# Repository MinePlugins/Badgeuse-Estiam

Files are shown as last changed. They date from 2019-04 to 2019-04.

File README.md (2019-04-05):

# Badgeuse-Estiam  :credit_card: 	

Réalisation complète du code de la badgeuse (API Désactivé et Token retiré)

# Dépendences  :package:

- Python 3
  - Flask
  - Flask_SocketIO
  - graphqlclient
  - PySerial
- Lecteur RFID Arduino (Le code à upload est dans Arduino)

# Matériels  :package:

- Ecran 7" HDMI
- Un Raspberry Pi
- Un Arduino
- Un RFID Reader RC522
- Des badges RFID (Mifare classic)

# Montage du Lecteur  :wrench:

```text
RC522   | Arduino Pin
  VCC   |  +5V
  RST   |   9
  GND   |   GND
  MISO  |   12
  MOSI  |   11
  SCK   |   13
  NSS   |   10
  IRC   |   /
  ```

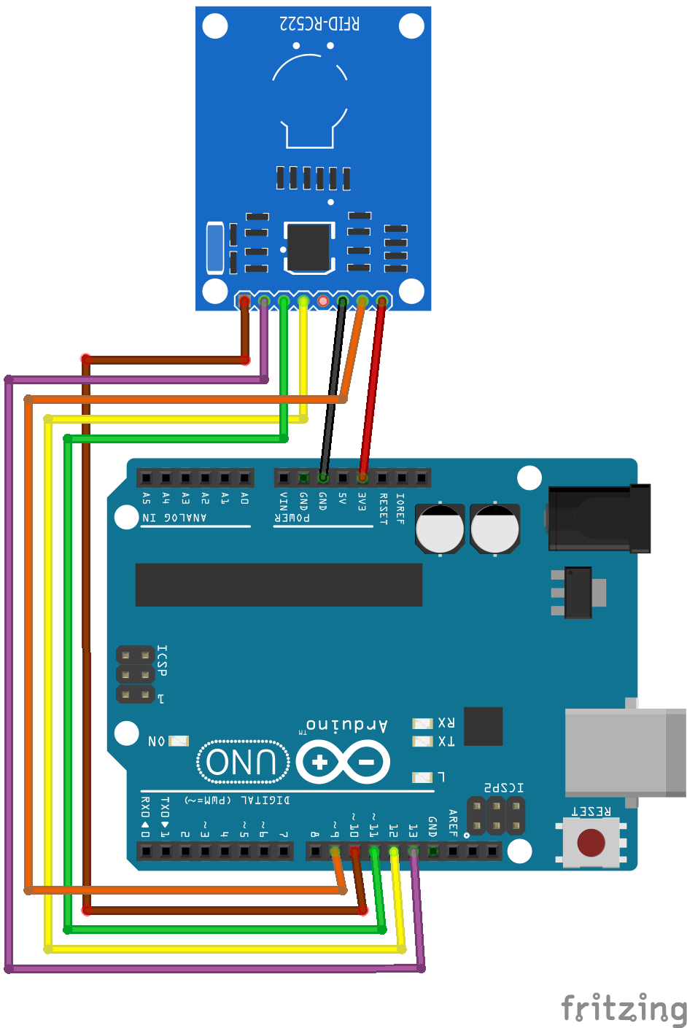
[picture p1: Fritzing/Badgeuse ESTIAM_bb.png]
Montage


# Configuration du Raspberry Pi:strawberry: :pencil2:
Tous d'abord il faut téléchargé le projet et l'installer sur le Raspberry Pi :
```bash
sudo apt-get install git python3-pip -y
sudo git clone https://github.com/MinePlugins/Badgeuse-Estiam
pip install -r requirements.txt
```
Puis il faut faire démarrer le script python, chromium en mode kiosk et de désactiver la souris à chaque démarrage
pour ce faire il faut édité le fichier `/home/pi/.config/lxsession/LXDE-pi○/autostart`.
Remplacer les lignes par celle-ci :

```bash
@python3 /home/pi/app.py
@sleep 10
@chromium-browser --incognito --kiosk http://127.0.0.1:8000
@unclutter -idle 0
```

Puis pour préserver la planète :earth_americas: nous allons faire une tâche cron qui éteint l'écran tous les soir à 19h du lundi au vendredi et une autre tâche qui allume tous les jour du lundi au vendredi à 8h

```bash
crontab -e

0 8 * * 1-5 vcgencmd display_power 1 >/dev/null 2>&1
0 19 * * 1-5 vcgencmd display_power 0 >/dev/null 2>&1

```

Enfin redémmarer les Raspberry Pi normalement tous s'allume correctement (si il est connecté à internet)
```bash
sudo reboot
```
# UI

[Lien .pdf du design](https://github.com/MinePlugins/Badgeuse-Estiam/raw/master/Design/Design%20Badgeuse.pdf)

## Présentation

Voilà le résultat final :

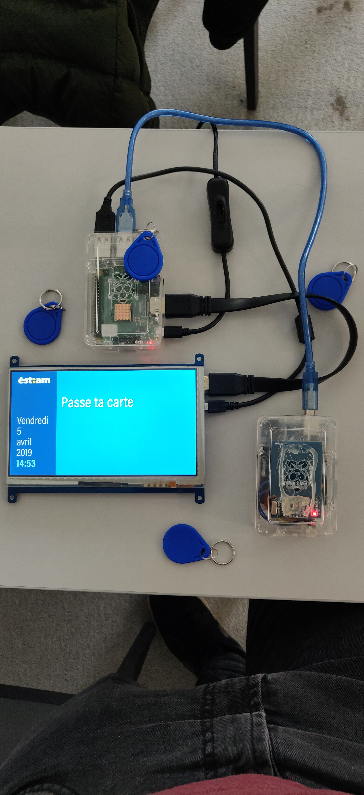
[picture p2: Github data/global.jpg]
Final


En cas d'erreur :

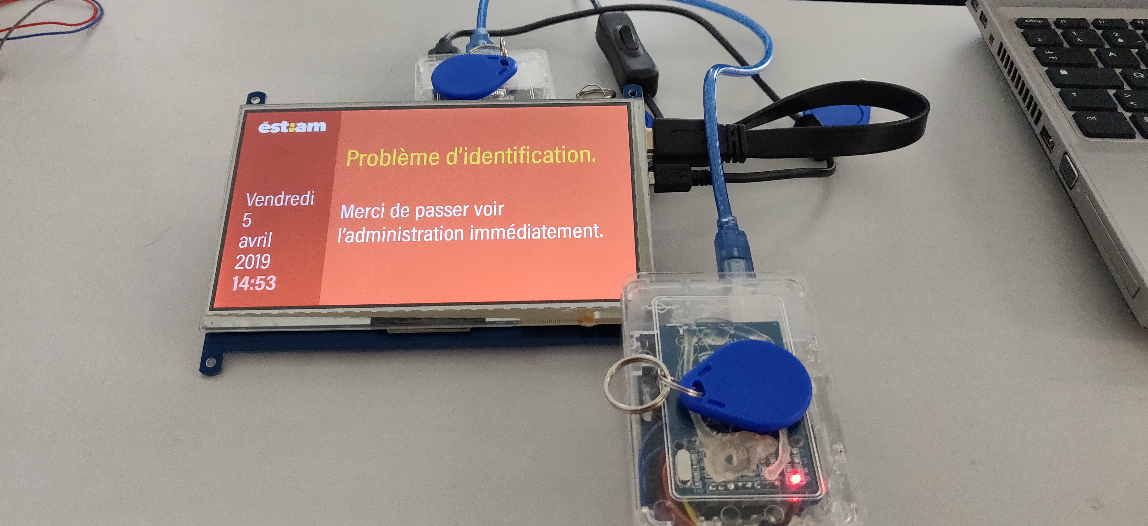
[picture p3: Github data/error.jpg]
Error


En en fonctionnement normal :

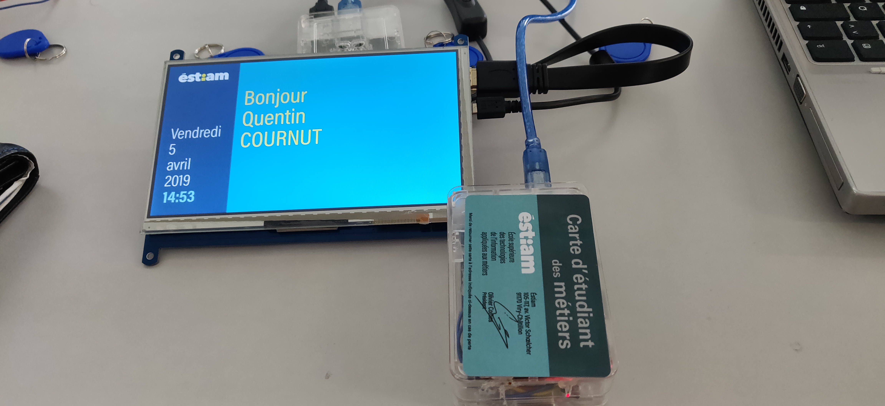
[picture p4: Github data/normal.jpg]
Normal


En cas de dysfonctionnement :

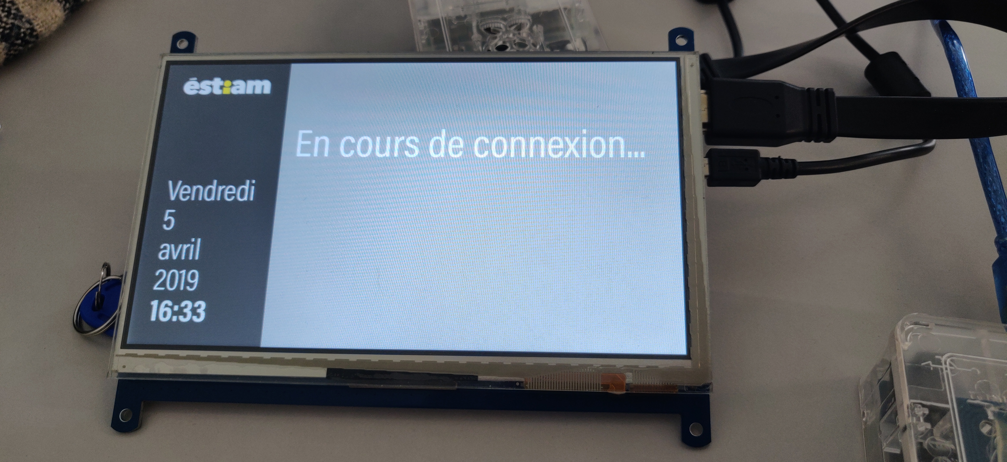
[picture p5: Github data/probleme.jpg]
Dys


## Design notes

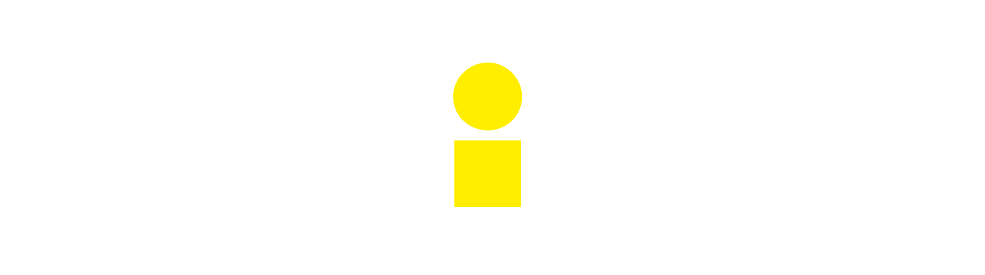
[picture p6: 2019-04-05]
static/e263796130a8c5083d48e29151d031ba.png

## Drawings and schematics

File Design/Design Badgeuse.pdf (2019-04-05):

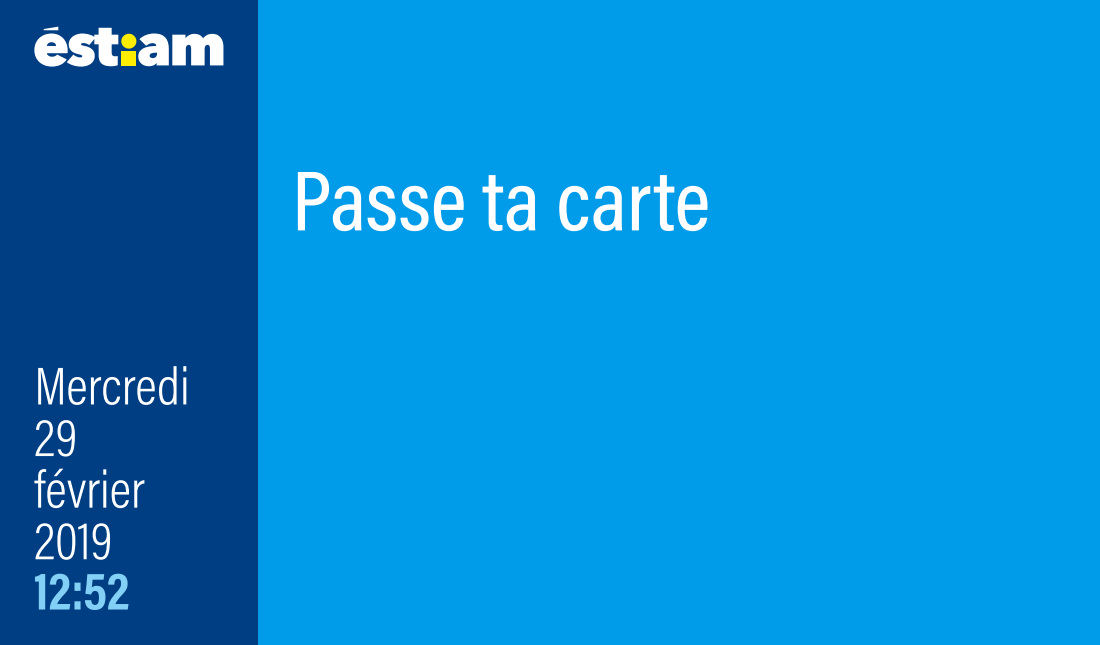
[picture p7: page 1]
Mercredi 29 février 2019 12:52

Passe ta carte

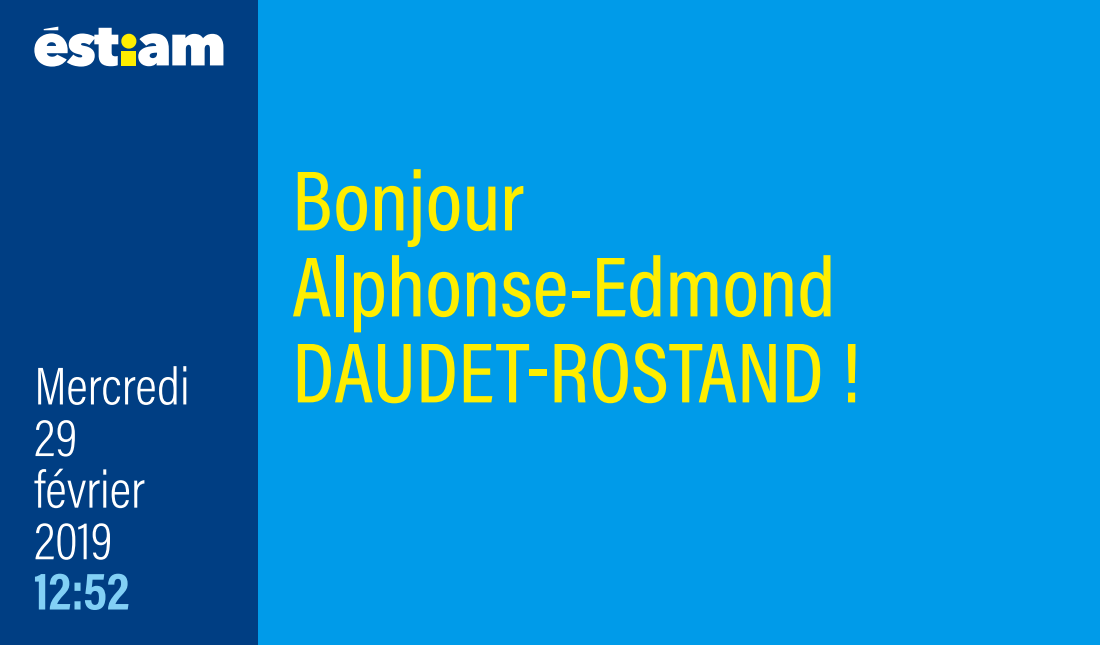
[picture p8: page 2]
Bonjour Alphonse-Edmond; Mercredi; DAUDET-ROSTAND !; 29 février 2019 12:52

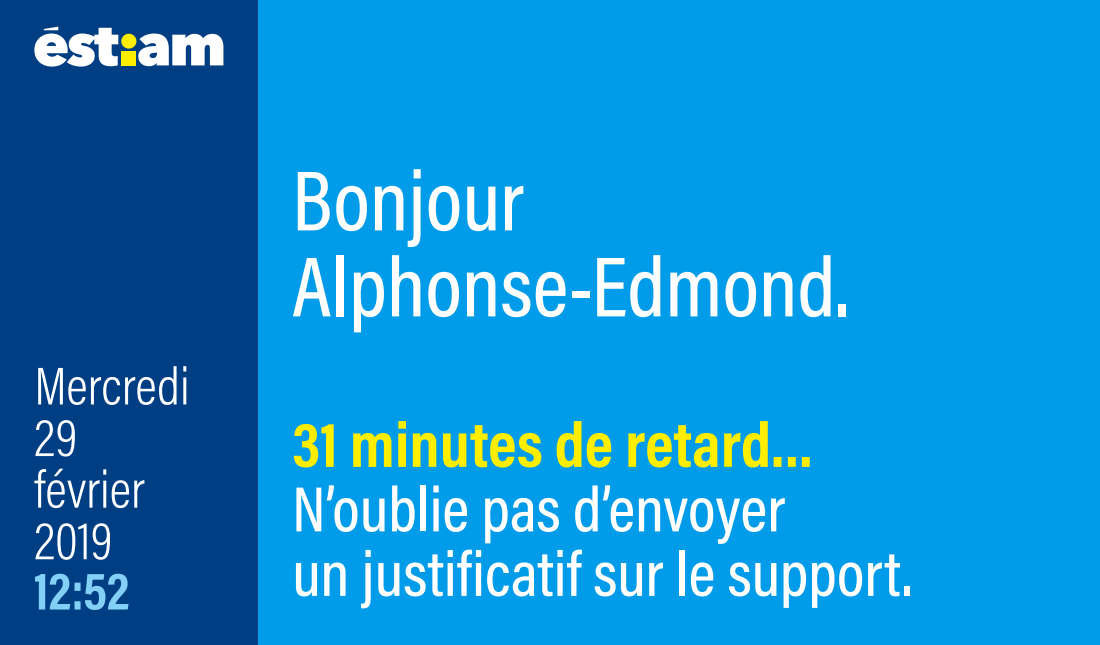
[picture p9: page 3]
Bonjour Alphonse-Edmond.; Mercredi 29 février 2019 12:52

31 minutes de retard…
N’oublie pas d’envoyer
un justificatif sur le support.

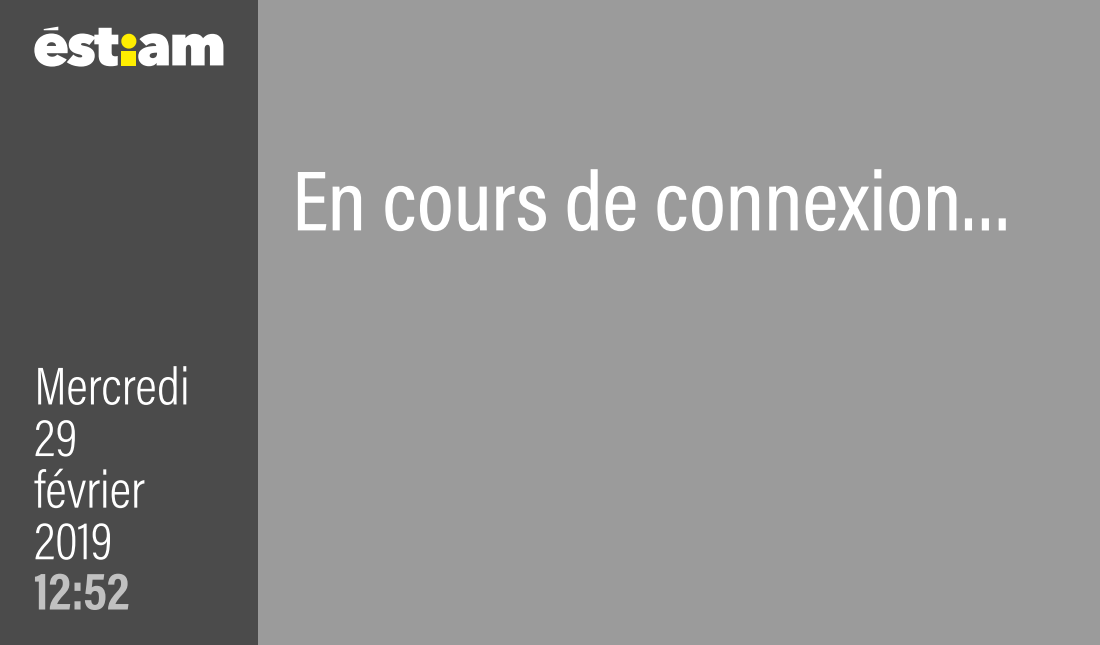
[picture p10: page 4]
Mercredi 29 février 2019 12:52

En cours de connexion…

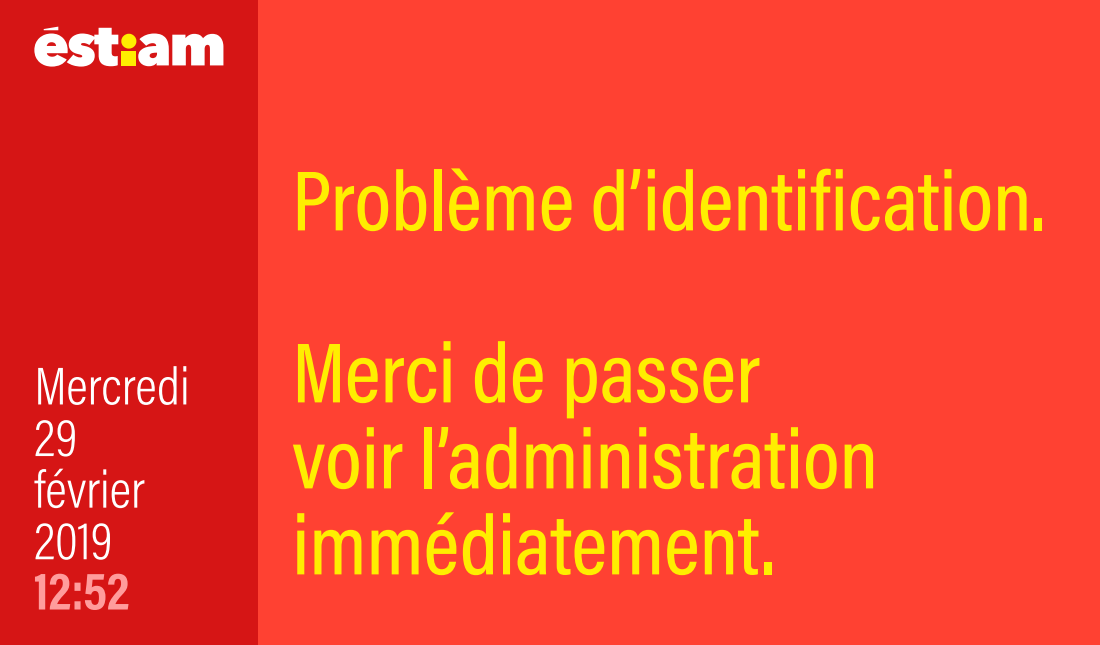
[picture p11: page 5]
Mercredi 29 février

Problème d’identification.
Merci de passer
voir l’administration
immédiatement. 12:52

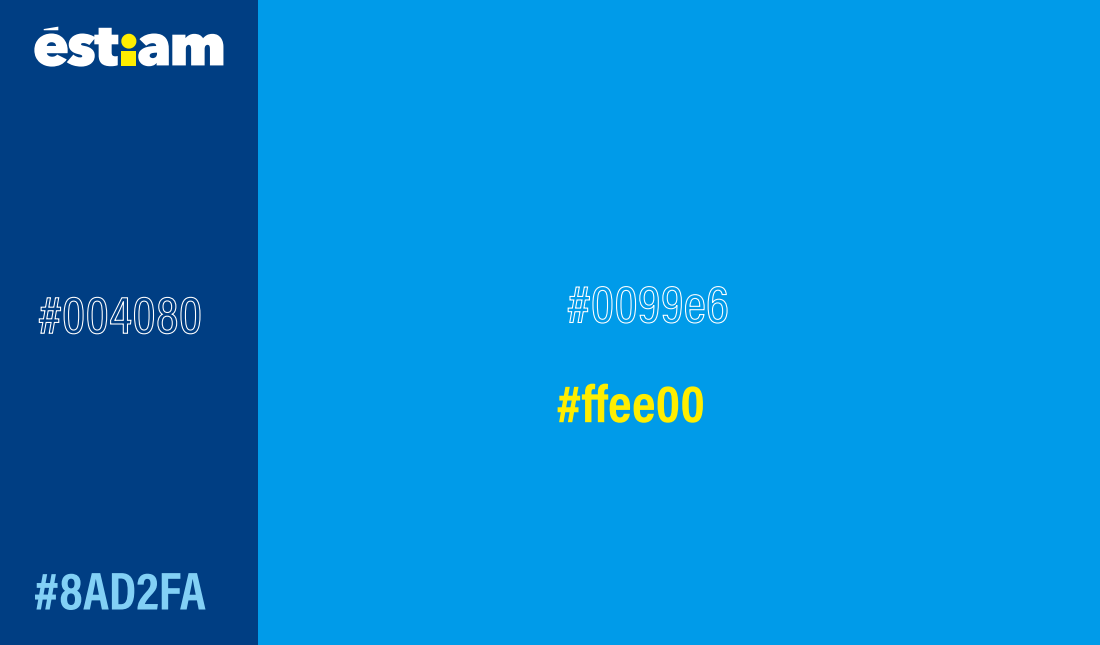
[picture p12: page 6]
#ffee00

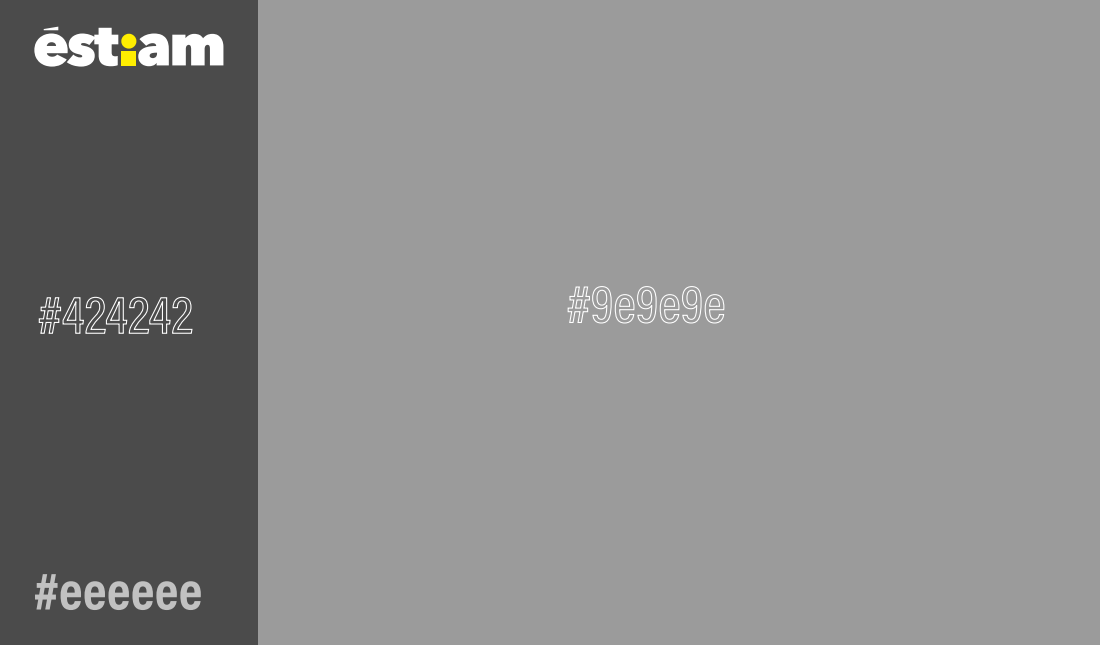
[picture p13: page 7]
#eeeeee

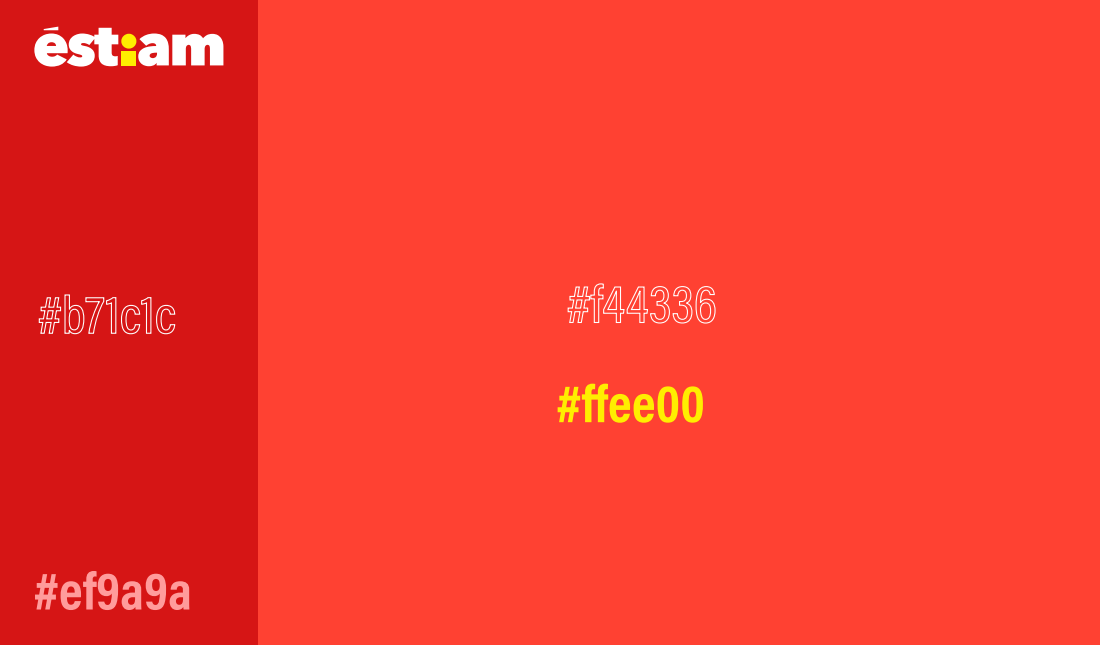
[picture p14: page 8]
#ffee00

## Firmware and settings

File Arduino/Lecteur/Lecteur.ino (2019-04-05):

#include <SPI.h>
#include <RFID.h>
#include <ArduinoJson.h>
/*
RC522   | Arduino Pin
  VCC   |  +5V
  RST   |   9
  GND   |   GND
  MISO  |   12
  MOSI  |   11
  SCK   |   13
  NSS   |   10
  IRC   |   /
*/
RFID rfid(10,9); // Pin du lecteur de carte

int UID[5]; // Taille de l'uid

void setup()
{
  Serial.begin(9600); // Vitesse de la liaison série
  SPI.begin(); // Initialisation de la communication SPI
  rfid.init();  // Initialisation du module RFID

}

void loop()
{
    StaticJsonDocument<256> data; // JSON data
    if (rfid.isCard()) {  // Si il y a une carte
          if (rfid.readCardSerial()) {        // Lire la carte
            data["uuid"] = "ESTIAM"+String(rfid.serNum[0])
                                   +String(rfid.serNum[1])
                                   +String(rfid.serNum[2])
                                   +String(rfid.serNum[3])
                                   +String(rfid.serNum[4]); // Formatter au format ESTIAM
            serializeJson(data, Serial); // Envoyé la donné en JSON
            Serial.println(); // Carriage return
          }          
          rfid.halt(); // Reset du lecteur de carte
    }
    
}

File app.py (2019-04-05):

# coding=utf-8
from flask import Flask, json, render_template
from threading import Thread
from flask_socketio import SocketIO
from graphqlclient import GraphQLClient
import serial, time, serial.tools.list_ports, datetime, socket


app = Flask(__name__)
app.config['SECRET_KEY'] = 'SECRET!'
socketio = SocketIO(app)
uuid_last = ''
data = ''
connexion_genius = GraphQLClient('https://##.###.##/')
connexion_genius.inject_token('Bearer ####','Authorization')
REMOTE_SERVER = "##.###.##"


@app.route('/')
def index():
    return render_template('index.html')


def is_connected():
  try:
    host = socket.gethostbyname(REMOTE_SERVER)
    socket.create_connection((host, 80), 2)
    return True
  except:
     pass
  return False

def getprofilewithbadge(badge):
    tmp = connexion_genius.execute('''{ 
                           profiles(where:{badge:"''' + badge + '''"}){
                           firstName
                           lastName
                         }
                       }
                    ''')
    return tmp

def sethello(badge):
    tmp = connexion_genius.execute('''mutation{terminalHello(data:{badge:"''' + badge + '''",timeOfArrival:"''' + str(datetime.datetime.now().isoformat()) + '''"}){status}}''')
    return tmp


class SerialRead(Thread):
    global j

    def __init__(self):
        Thread.__init__(self)

        ports = list(serial.tools.list_ports.comports())
        for p in ports:
            if "Arduino" in p[1] or "ttyACM0" in p[1]:
                print("Arduino detecte sur le port : ", p[0])
                self.serial = serial.Serial(str(p[0]), 9600, timeout=1)
                socketio.emit('Internet', {'internet': True})

    def init_serial(self):
        ports = list(serial.tools.list_ports.comports())
        self.serial.close()
        for p in ports:
            if "Arduino" in p[1] or "ttyACM0" in p[1]:
                print("Arduino detecte sur le port : ", p[0])
                self.serial = serial.Serial(str(p[0]), 9600, timeout=1)
                socketio.emit('Internet', {'internet': True})
                self.run()

    def run(self):
        global uuid_last
        while True:
            try:
                if self.serial is not None:

                    data = self.serial.readline().strip(b'\n\r')
                    try:
                        if is_connected():
                            j = json.loads(data.decode('UTF-8'))
                            socketio.emit('Internet', {'internet': True})
                            if "ESTIAM" in j['uuid']:
                                if uuid_last != j['uuid']:
                                    uuid_last = j['uuid']
                                    try:
                                        reponse = json.loads(sethello(uuid_last))
                                        try:
                                            if len(reponse['errors']) > 0:
                                                socketio.emit('CardFound', {'error':True,'user': None, 'late':False})
                                        except:
                                            if reponse['data']['terminalHello']['status'] == "OK":
                                                profile = json.loads(getprofilewithbadge(uuid_last))
                                                socketio.emit('CardFound', {'error':False,'user': {'firstName': profile['data']['profiles'][0]['firstName'],'lastName': profile['data']['profiles'][0]['lastName'],'late': None}, 'late':False})
                                            if reponse['data']['terminalHello']['status'] == "ALREADYBADGED":
                                                profile = json.loads(getprofilewithbadge(uuid_last))
                                                socketio.emit('CardFound', {'error':False,'user': {'firstName': profile['data']['profiles'][0]['firstName'],'lastName': profile['data']['profiles'][0]['lastName'],'late': None}, 'late':False})
                                            if reponse['data']['terminalHello']['status'] == "NO_DATE":
                                                profile = json.loads(getprofilewithbadge(uuid_last))
                                                socketio.emit('CardFound', {'error':False,'user': {'firstName': profile['data']['profiles'][0]['firstName'],'lastName': profile['data']['profiles'][0]['lastName'],'late': None}, 'late':False})
                                            if reponse['data']['terminalHello']['status'] == "UNKNOWN_CARD":
                                                socketio.emit('CardFound', {'error':True,'user':False,'late':False})
                                            if reponse['data']['terminalHello']['status'] == "FAILED_SYS_ERROR":
                                                socketio.emit('CardFound', {'error': True, 'user': False, 'late': False})

                                    except:
                                        continue

                        else:
                            socketio.emit('Internet', {'internet': False})

                    except:
                        continue
            except:
                socketio.emit('Internet', {'internet': False})
                print("La liaison serie ne peut etre etablie")
                time.sleep(1)
                self.init_serial()

    def first(self):
        self.run()


if __name__ == '__main__':
    ThreadSerial = SerialRead()
    ThreadSerial.start()
    socketio.run(app,host='0.0.0.0',port=8000)

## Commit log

2019-04-05 Code du lecteur Arduino
2019-04-05 Amélioration de la doc
    [Badgeuse ESTIAM.fzz]
